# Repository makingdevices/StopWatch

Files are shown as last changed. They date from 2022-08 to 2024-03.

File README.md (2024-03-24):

<!-- Improved compatibility of back to top link: See: https://github.com/othneildrew/Best-README-Template/pull/73 -->

<!--
*** Thanks for checking out the Best-README-Template. If you have a suggestion
*** that would make this better, please fork the repo and create a pull request
*** or simply open an issue with the tag "enhancement".
*** Don't forget to give the project a star!
*** Thanks again! Now go create something AMAZING! :D
-->

<!-- PROJECT SHIELDS -->
<!--
*** I'm using markdown "reference style" links for readability.
*** Reference links are enclosed in brackets [ ] instead of parentheses ( ).
*** See the bottom of this document for the declaration of the reference variables
*** for contributors-url, forks-url, etc. This is an optional, concise syntax you may use.
*** https://www.markdownguide.org/basic-syntax/#reference-style-links
-->
[][ig-url]
[][sponsor-url]
[][stars-url]
[][issues-url]
[][linkedin-url]

<!-- PROJECT LOGO -->
<br />
<div align="center">
  <a href="https://makingdevices.com/links/">
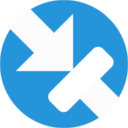
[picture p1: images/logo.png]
    
  </a>

<h3 align="center">Making Devices</h3>

  <p align="center">
    Open Source projects where we struggle with engineering, electronics, coding and who knows what else... In this case, Bytes Counter is a very simple digital tally counter, so hopefully you may find it interesting ;)
  </p>
</div>

<!-- TABLE OF CONTENTS -->
<details>
  <summary>Table of Contents</summary>
  <ol>
    <li>
      <a href="#about-the-project">About The Project</a>
      <ul>
        <li><a href="#built-with">Built With</a></li>
      </ul>
    </li>
    <li>
      <a href="#Build-one">Build one</a>
      <ul>
      </ul>
    </li>
    <li><a href="#usage">Usage</a></li>
    <li><a href="#roadmap">Roadmap</a></li>
    <li><a href="#license">License</a></li>
    <li><a href="#contact">Contact</a></li>
    <li><a href="#Sponsor">Sponsor</a></li>
  </ol>
</details>

<!-- ABOUT THE PROJECT -->
## About The Project

[Bytes Counter Shot](https://makingdevices.com/StopWatch)

This project is a simple StopWatch for measuring times on different processes or activities. The project was chosen to test some 4-layers PCBs and experiment with both the XLP (Extreme Low-Power Technology) and the pic18LF14k50 itself. You can measure from milliseconds to more than 99h. 

The PCB does not have any power button, since the project's approach is to use the XLP technology of the PIC. It only has two buttons: start/mode button and pause/stop button.

<p align="right">(<a href="#readme-top">back to top</a>)</p>

### Built With

[][PIC-url]
[][MPLAB-C-url]
[][kicad-url]
[][sponsor-url]

<p align="right">(<a href="#readme-top">back to top</a>)</p>

<!-- GETTING STARTED -->

## Build one

1. Get the gerber files for the latest version: [V1](https://github.com/makingdevices/StopWatch/blob/main/v1/Gerber/StopWatchV1.zip) 
2. Send them to a PCB manufacturer ([Our Sponsor is PCBWAY][sponsor-url])
3. Buy all the components from the [Bill Of Materials](https://github.com/makingdevices/StopWatch/blob/main/v1/StopWatch_BOM.xlsx)
4. Solder everything with the help of the [schematic](https://github.com/makingdevices/StopWatch/blob/main/v1/schematicv1.pdf)
5. Burn the [latest firmware](https://github.com/makingdevices/StopWatch/blob/main/v1/Simulation/StopWatch.hex)
6. Give us a Star to the respository ;)

Here it is an assembly video:

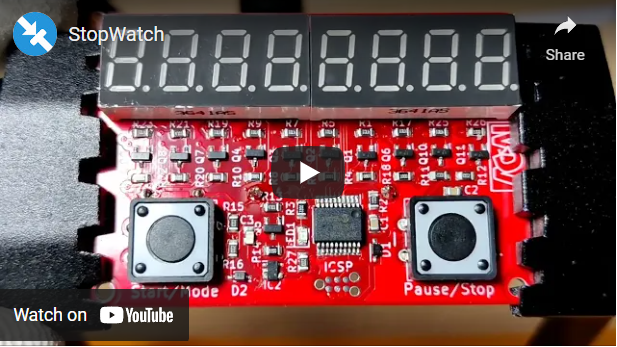
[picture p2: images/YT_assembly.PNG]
Assembly Shot
[](https://www.youtube.com/watch?v=HLl4U4vhF9I)

<p align="right">(<a href="#readme-top">back to top</a>)</p>

<!-- USAGE EXAMPLES -->
## Usage

Instructions of use:

- Pressing "Start" will start the StopWatch.
- Pressing "Pause" will stop the StopWatch.
- Long press "Start" : it will change the display mode.
- Long press "Stop" : It will reset the time to 0.
- 60s without pressing any button: Save Energy Mode -> Display off. It will still count the time. 
- 10s without pressing any button in pause mode: Deep Sleep Mode -> Display off. Not counting

<p align="right">(<a href="#readme-top">back to top</a>)</p>

<!-- ROADMAP -->
## Roadmap

- [x] Stopwatch and show it on screen
- [x] enable/disable sound when pressing buttons
- [x] Low Power Consumption
    - [x] Lower the frequency of the microcontroller at minimum
    - [x] Enter deep sleep mode automatically
    - [x] Save energy mode while still working: Display off
- [x] Measure power consumption

See the [open issues](https://github.com/makingdevices/StopWatch/issues) for a full list of proposed features (and known issues).

State: Project <b>FINISHED</b> - 18/08/2022

<p align="right">(<a href="#readme-top">back to top</a>)</p>

<!-- LICENSE -->
## License

## License

Distributed under three licenses:
- [Hardware](/License/HW_cern_ohl_s_v2.pdf)
- [Software](/License/SW_GPLv3.0.txt)
- [Documentation](/License/Documentation_CC-BY-SA-4.0.txt)

[GPL v3 License][license-url] 
<p align="right">(<a href="#readme-top">back to top</a>)</p>

<!-- CONTACT -->
## Contact

Making Devices - [@MakingDevices](https://www.instagram.com/makingdevices/)

Project Link: [https://github.com/makingdevices/StopWatch](https://github.com/makingdevices/StopWatch)

Other Links: [LinkTree](https://makingdevices.com/links/)

<p align="right">(<a href="#readme-top">back to top</a>)</p>

<!-- Sponsor -->
## Sponsor

PCBWay is the most professional PCB manufacturer for prototyping and low-volume production to work with in the world. With more than a decade in the field, They are committed to meeting the needs of their customers from different industries in terms of quality, delivery, cost-effectiveness and any other demanding requests. As Sponsor of Making Devices, they will be in charge of all the PCBs for MDV, allowing both of us to grow together in a long term partnership. We hope you take them into account for your both personal and professional prototypes or products.

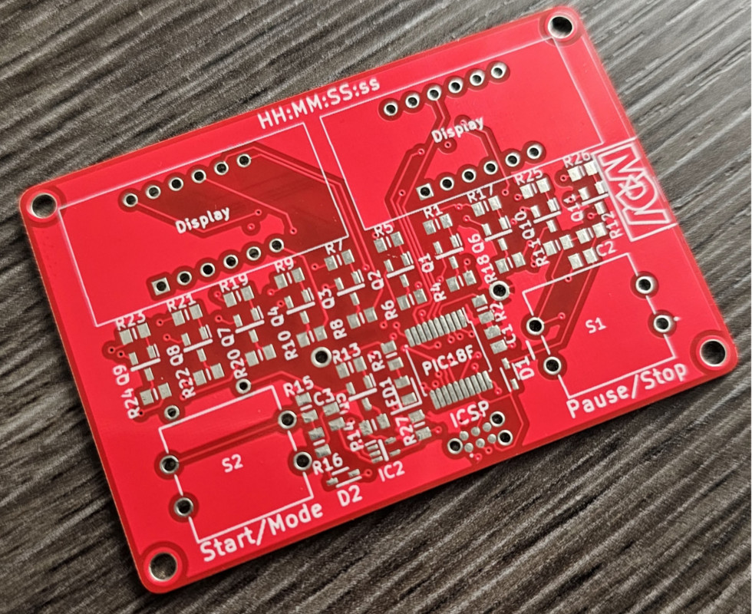
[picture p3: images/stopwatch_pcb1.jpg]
Sponsor Shot
[][sponsor-url]
[Sponsor Shot][sponsor-url]

<p align="right">(<a href="#readme-top">back to top</a>)</p>

<!-- MARKDOWN LINKS & IMAGES -->
<!-- https://www.markdownguide.org/basic-syntax/#reference-style-links -->
[contributors-shield]: https://img.shields.io/github/contributors/makingdevices/StopWatch.svg?style=for-the-badge
[contributors-url]: https://github.com/makingdevices/StopWatch/graphs/contributors
[forks-shield]: https://img.shields.io/github/forks/makingdevices/StopWatch.svg?style=for-the-badge
[forks-url]: https://github.com/makingdevices/StopWatch/network/members
[stars-shield]: https://img.shields.io/github/stars/makingdevices/StopWatch.svg?style=for-the-badge
[stars-url]: https://github.com/makingdevices/StopWatch/stargazers
[issues-shield]: https://img.shields.io/github/issues/makingdevices/StopWatch.svg?style=for-the-badge
[issues-url]: https://github.com/makingdevices/StopWatch/issues
[license-shield]: /images/license.png
[license-url]: https://github.com/makingdevices/StopWatch/tree/main/License
[linkedin-shield]: https://img.shields.io/badge/-LinkedIn-black.svg?style=for-the-badge&logo=linkedin&colorB=555
[linkedin-url]: https://www.linkedin.com/company/making-devices/
[sponsor-shield]: https://img.shields.io/badge/SPONSOR-PCBWAY-black.svg?style=for-the-badge&colorB=1200
[sponsor-url]: https://www.pcbway.com/?from=makingdevices
[sponsor-screenshot-pcb1]: /images/stopwatch_pcb1.jpg
[sponsor-screenshot-pcb2]: /images/stopwatch_pcb2.jpg
[product-screenshot]: images/screenshot.gif
[PIC]: https://img.shields.io/badge/PIC18LF14K50-000000?style=for-the-badge
[PIC-url]: http://ww1.microchip.com/downloads/en/devicedoc/40001350f.pdf
[kicad-shield]: https://img.shields.io/badge/kicad-0b03fc?style=for-the-badge&logo=kicad&logoColor=white
[kicad-url]: https://www.kicad.org/
[YT-screenshot]: images/YT_assembly.PNG
[sponsor-icon]:  https://img.shields.io/badge/-PCBWAY-black.svg?style=for-the-badge&colorB=1200
[ig-shield]: https://img.shields.io/badge/instagram-a83297?style=for-the-badge&logo=instagram&logoColor=white
[ig-url]: https://www.instagram.com/makingdevices/
[MPLAB-C]: https://img.shields.io/badge/MPLAB%20C18-DD0031?style=for-the-badge&logo=C&logoColor=white
[MPLAB-C-url]: https://www.microchip.com/en-us/development-tool/SW006011
[Svelte.dev]: https://img.shields.io/badge/Svelte-4A4A55?style=for-the-badge&logo=svelte&logoColor=FF3E00
[Svelte-url]: https://svelte.dev/
[Laravel.com]: https://img.shields.io/badge/Laravel-FF2D20?style=for-the-badge&logo=laravel&logoColor=white
[Laravel-url]: https://laravel.com
[Bootstrap.com]: https://img.shields.io/badge/Bootstrap-563D7C?style=for-the-badge&logo=bootstrap&logoColor=white
[Bootstrap-url]: https://getbootstrap.com
[JQuery.com]: https://img.shields.io/badge/jQuery-0769AD?style=for-the-badge&logo=jquery&logoColor=white
[JQuery-url]: https://jquery.com

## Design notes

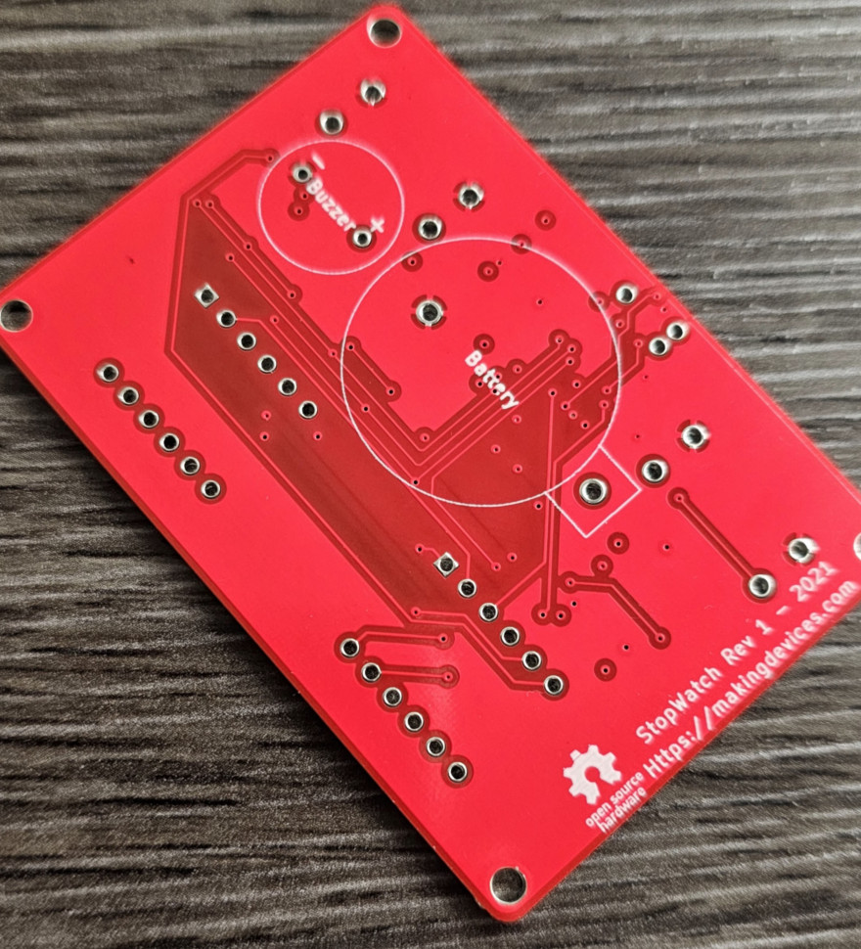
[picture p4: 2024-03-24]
images/stopwatch_pcb2.jpg

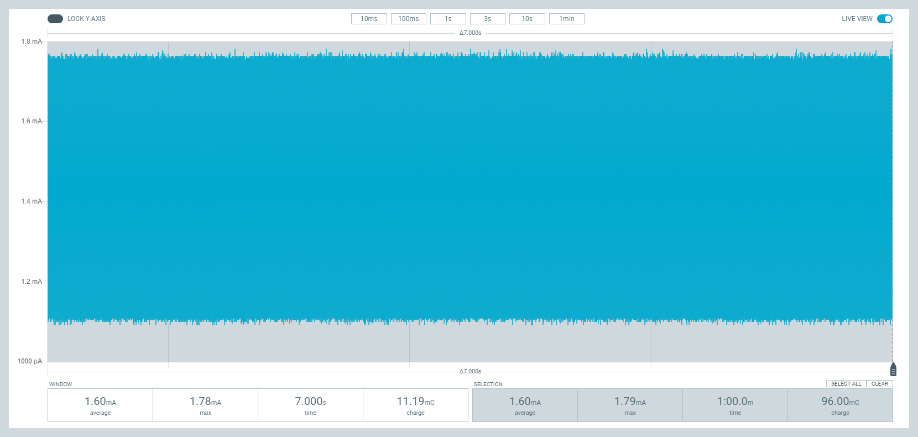
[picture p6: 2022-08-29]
v1/PowerProfile/Sleep_ScreenOFF_Counting.png

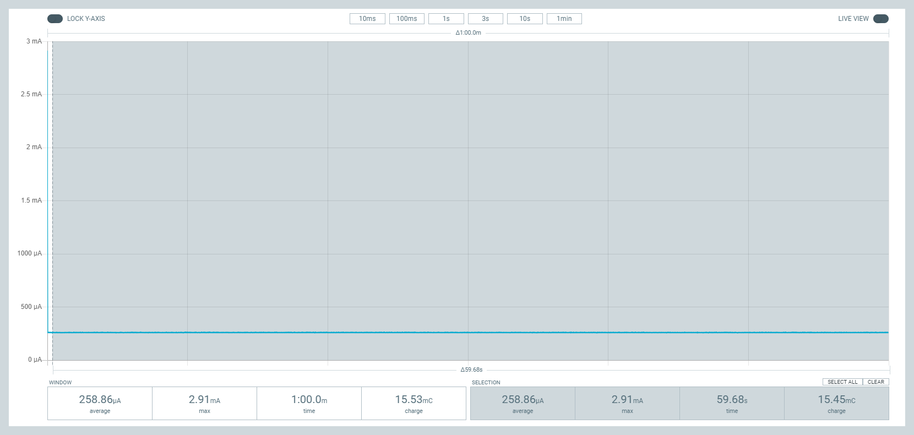
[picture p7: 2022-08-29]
v1/PowerProfile/ScreenOFF_NOTCounting.png

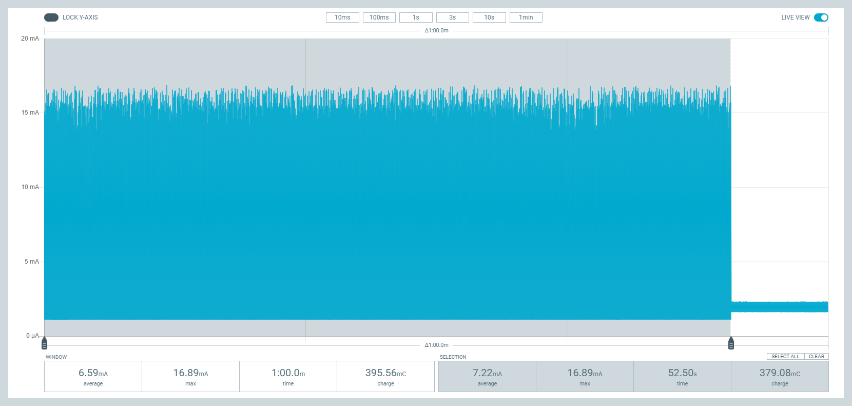
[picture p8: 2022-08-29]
v1/PowerProfile/ScreenON_Counting.png

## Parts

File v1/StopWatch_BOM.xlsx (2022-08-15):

Part | Info | Qty. | Unit Price | Ext. Price | LSCS | Link
PIC18LF14K50-I/PT | MicroProcessor | 1 | $2.0000 | $2.0000 | C219580 | https://lcsc.com/product-detail/Others_Microchip-Tech_PIC18F45K50-I-PT_Microchip-Tech-PIC18F45K50-I-PT_C219580.html
PCB v1 | PCBWAY | 1 | $3.0000 | $3.0000 |  | https://www.pcbway.com
TJ-S2012SW8TGLC2G-A5 | Green LED | 1 | $0.0291 | $0.0291 | C192319 | https://lcsc.com/product-detail/Others_TOGIALED-TJ-S2012SW8TGLC2G-A5_C192319.html
MMBT5551LT1G | NPN 600mA | 11 | $0.0250 | $0.2750 | C41095 | https://lcsc.com/product-detail/Bipolar-Transistors-BJT_ON-Semiconductor-ON-MMBT2222ALT3G_C416011.html
RTT052200FTP | 220 Ohm 0805 | 10 | $0.0024 | $0.0243 | C104105 | https://lcsc.com/product-detail/Chip-Resistor-Surface-Mount_220R-2200-1_C104105.html
NQ05W8J0101T5E | 100 Ohm 0805 | 1 | $0.0035 | $0.0035 | C965100
RTT054701FTP | 4.7k Ohm 0805 | 11 | $0.0042 | $0.0457 | C104344 | https://lcsc.com/product-detail/Chip-Resistor-Surface-Mount_4-7KR-4701-1_C104344.html
0805W8F1002T5E | 10K 0805 | 6 | $0.0028 | $0.0166 | C38522 | https://lcsc.com/product-detail/Chip-Resistor-Surface-Mount_UNI-ROYAL-Uniroyal-Elec-0805W8F1002T5E_C38522.html
TMB12A05 | Buzzer 5V | 1 | $0.1893 | $0.1893 | C96093 | https://lcsc.com/product-detail/Buzzers_Jiangsu-Huaneng-Elec-TMB12A05_C96093.html
AC0805KRX7R9BB104 | 0.1uF Cap | 3 | $0.0198 | $0.0594 | C277502 | https://lcsc.com/product-detail/Others_YAGEO-AC0805KRX7R9BB104_C277502.html
cr2032 battery holder | 2032 Battery Holder | 1 | $0.0700 | $0.0700 |  | https://es.aliexpress.com/item/33029764816.html
3461AS | Display | 2 | $0.1900 | $0.3800 |  | https://es.aliexpress.com/item/32795459724.html?spm=a2g0s.9042311.0.0.274263c0RaCynT
Tactile Push Buttons | Buttons | 2 | $0.0750 | $0.1500 |  | https://www.banggood.com/200Pcs-Tactile-Push-Button-Switch-Momentary-Tact-Caps-p-1562278.html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
ZLLS410TA | Diodes | 2 | $0.2391 | $0.4782 | C177096 | https://lcsc.com/product-detail/Schottky-Barrier-Diodes-SBD_Diodes-Incorporated-ZLLS410TA_C177096.html
74LVC1G06GW,125 | Inverter - open-drain out | 1 | $0.0534 | $0.0534 | C426704 | https://lcsc.com/product-detail/Buffers-Drivers_Nexperia-74LVC1G06GW-125_C426704.html
 |  |  |  | Total: | $6.7745

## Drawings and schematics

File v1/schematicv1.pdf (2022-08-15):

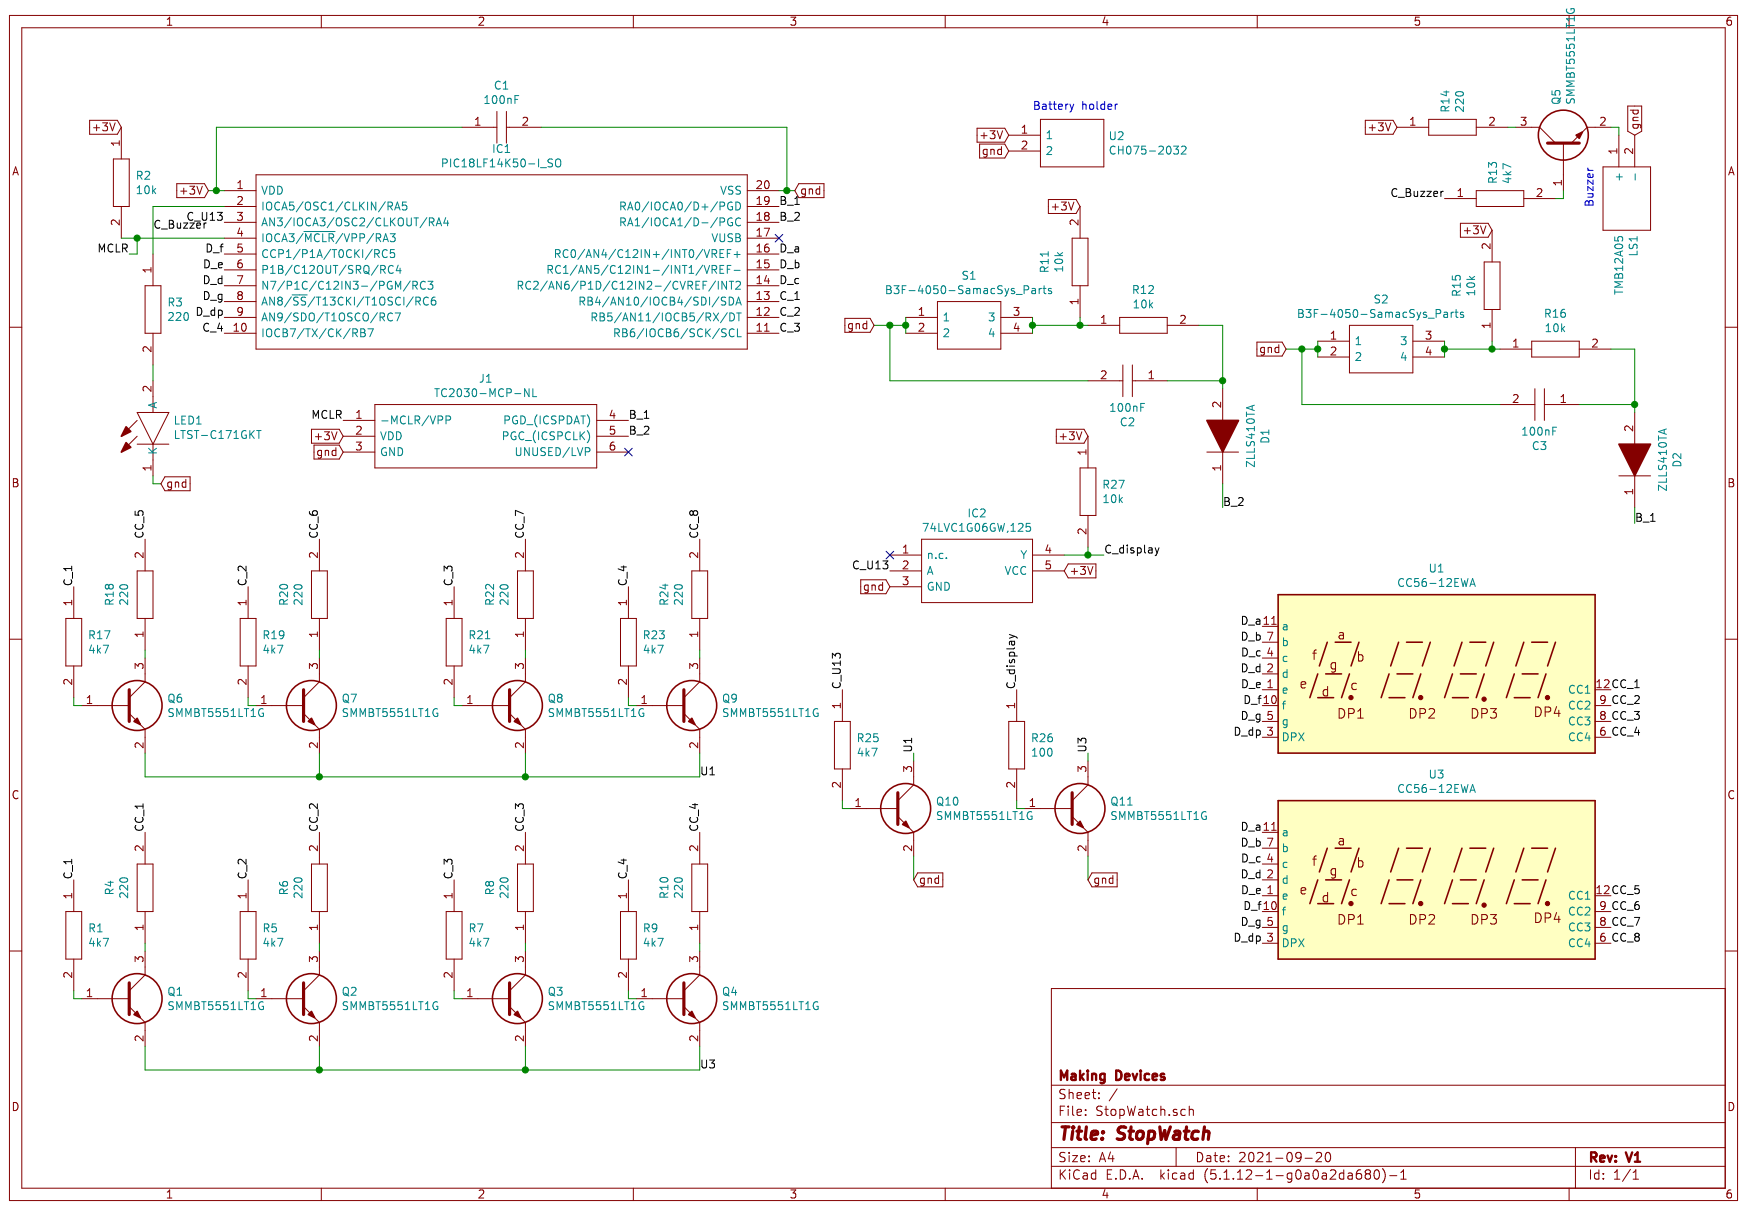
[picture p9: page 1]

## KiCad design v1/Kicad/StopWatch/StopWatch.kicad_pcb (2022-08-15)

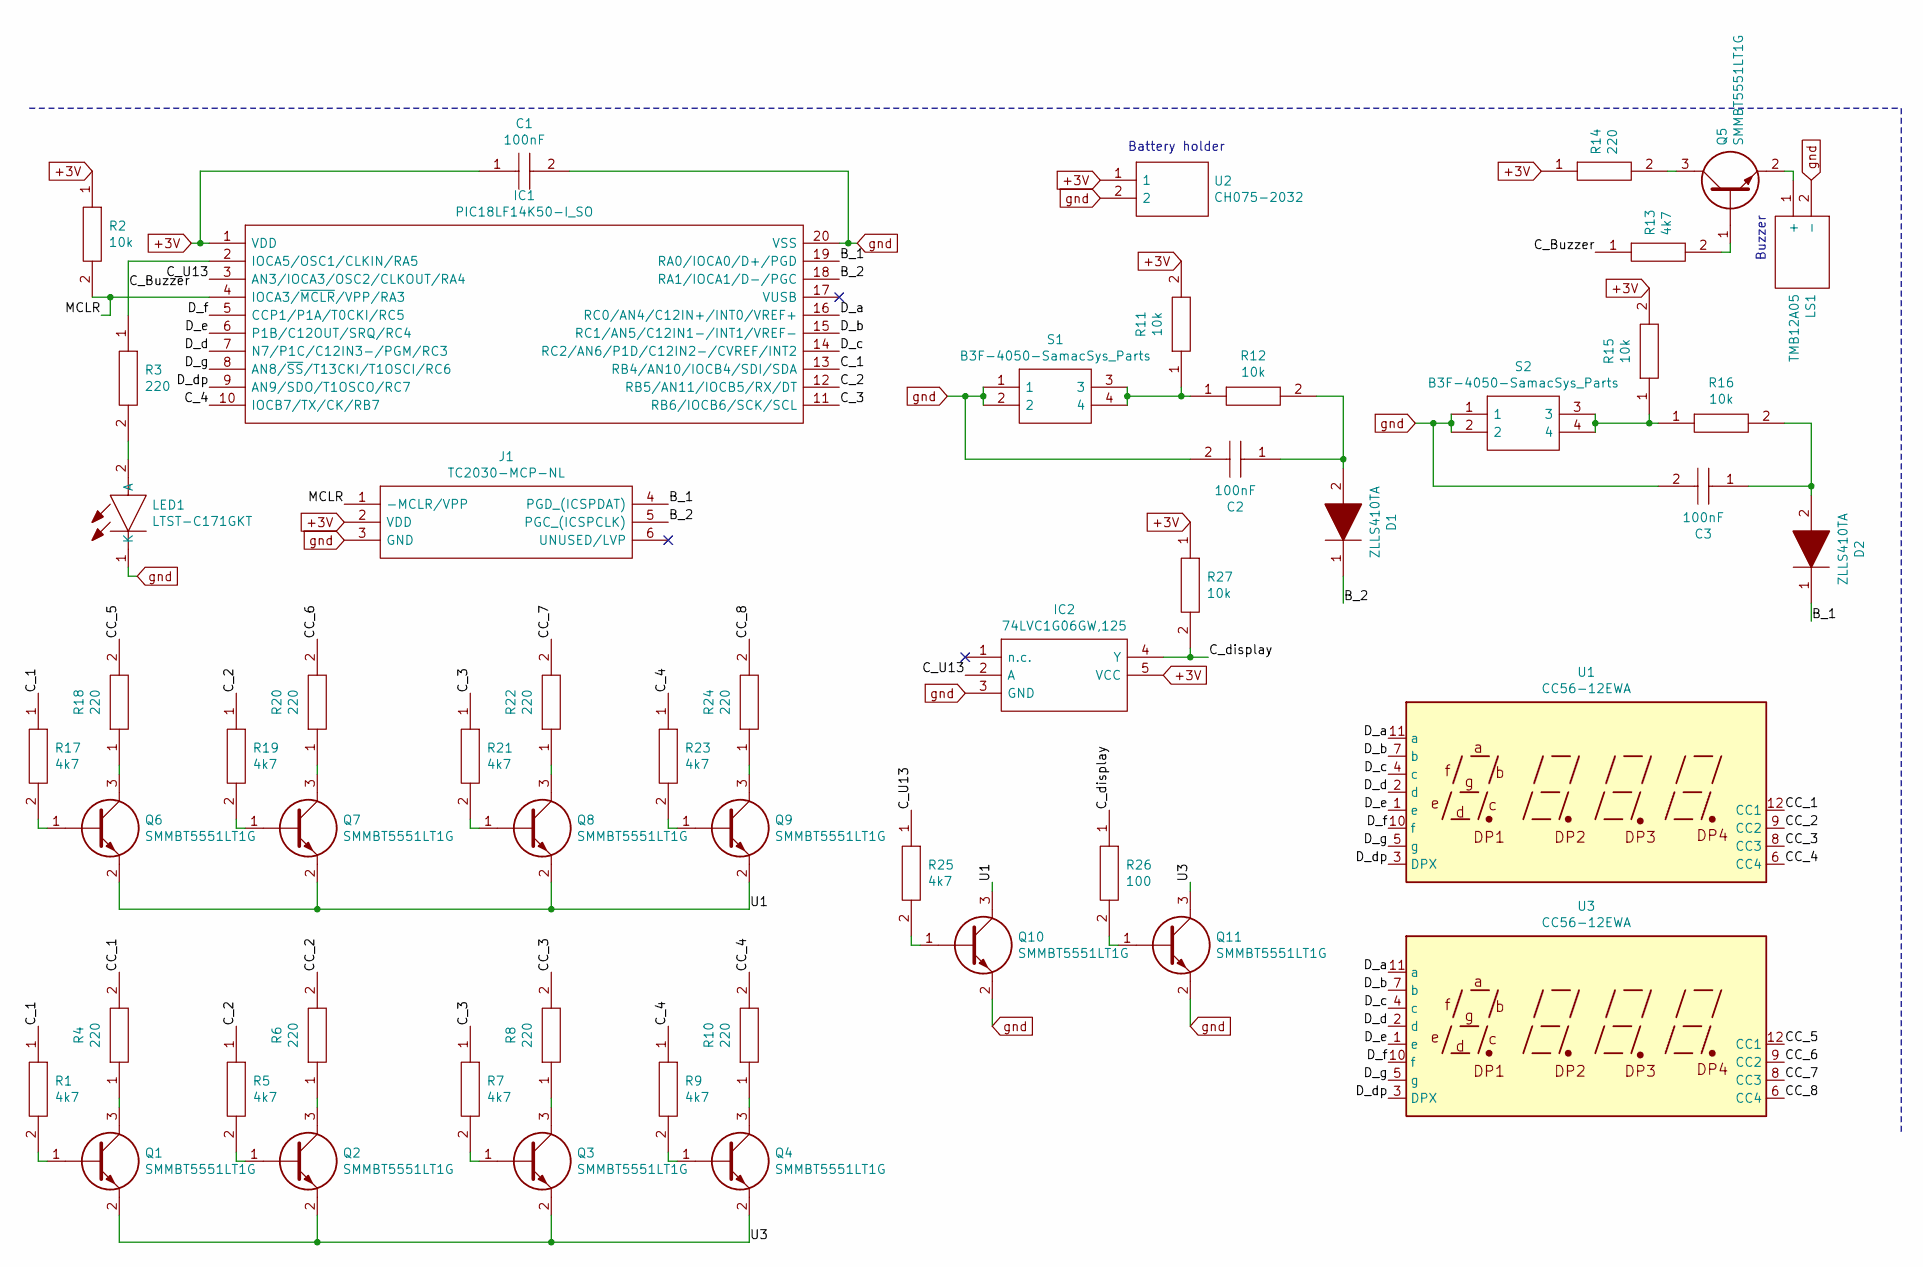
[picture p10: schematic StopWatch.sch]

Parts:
C1, C2, C3: 100nF; CAPC2012X145N; Manufacturer_Part_Number GCG21BR71H154KA01K
D1, D2: ZLLS410TA; SOD2513X120N; Manufacturer_Part_Number ZLLS410TA
IC1: PIC18LF14K50-I_SO; SSOP-20_5.3x7.2mm_P0.65mm; Manufacturer_Part_Number PIC18LF14K50-I/SO
IC2: 74LVC1G06GW,125; SOT65P212X110-5N; Manufacturer_Part_Number 74LVC1G06GW,125
J1: TC2030-MCP-NL; Manufacturer_Part_Number TC2030-MCP-NL
LED1: LTST-C171GKT; LEDC2012X90N; Manufacturer_Part_Number LTST-C171GKT
LS1: TMB12A05; Manufacturer_Part_Number TMB12A05
Q1, Q2, Q3, Q4, Q5, Q6, Q7, Q8, Q9, Q10, Q11: SMMBT5551LT1G; SOT96P237X111-3N; Manufacturer_Part_Number SMMBT5551LT1G
R1, R5, R7, R9, R13, R17, R19, R21, R23, R25: 4k7; RESC2012X65N; Manufacturer_Part_Number KTR10EZPF4220
R2, R11, R12, R15, R16, R27: 10k; RESC2012X65N; Manufacturer_Part_Number KTR10EZPF4220
R3, R4, R6, R8, R10, R14, R18, R20, R22, R24: 220; RESC2012X65N; Manufacturer_Part_Number KTR10EZPF4220
R26: 100; RESC2012X65N; Manufacturer_Part_Number KTR10EZPF4220
S1, S2: B3F-4050-SamacSys_Parts; B3F-4000; Manufacturer_Part_Number B3F-4050; Mouser Part Number 653-B3F-4050
U1, U3: CC56-12EWA; CA56-12EWA
U2: CH075-2032; CH0752032; Manufacturer_Part_Number CH075-2032

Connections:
+3V: C1.1, IC1.1 (VDD), IC2.5 (VCC), J1.2 (VDD), R2.1, R11.2, R14.1, R15.2, R27.1, U2.1
/B_1: D2.1, IC1.19 (RA0/IOCA0/D+/PGD), J1.4 (PGD_(ICSPDAT))
/B_2: D1.1, IC1.18 (RA1/IOCA1/D-/PGC), J1.5 (PGC_(ICSPCLK))
/CC_1: R4.2, U1.12 (CC1)
/CC_2: R6.2, U1.9 (CC2)
/CC_3: R8.2, U1.8 (CC3)
/CC_4: R10.2, U1.6 (CC4)
/CC_5: R18.2, U3.12 (CC1)
/CC_6: R20.2, U3.9 (CC2)
/CC_7: R22.2, U3.8 (CC3)
/CC_8: R24.2, U3.6 (CC4)
/C_1: IC1.13 (RB4/AN10/IOCB4/SDI/SDA), R1.1, R17.1
/C_2: IC1.12 (RB5/AN11/IOCB5/RX/DT), R5.1, R19.1
/C_3: IC1.11 (RB6/IOCB6/SCK/SCL), R7.1, R21.1
/C_4: IC1.10 (IOCB7/TX/CK/RB7), R9.1, R23.1
/C_Buzzer: IC1.2 (IOCA5/OSC1/CLKIN/RA5), R3.1, R13.1
/C_U13: IC1.3 (AN3/IOCA3/OSC2/CLKOUT/RA4), IC2.2 (A), R25.1
/C_display: IC2.4 (Y), R26.1, R27.2
/D_a: IC1.16 (RC0/AN4/C12IN+/INT0/VREF+), U1.11 (a), U3.11 (a)
/D_b: IC1.15 (RC1/AN5/C12IN1-/INT1/VREF-), U1.7 (b), U3.7 (b)
/D_c: IC1.14 (RC2/AN6/P1D/C12IN2-/CVREF/INT2), U1.4 (c), U3.4 (c)
/D_d: IC1.7 (N7/P1C/C12IN3-/PGM/RC3), U1.2 (d), U3.2 (d)
/D_dp: IC1.9 (AN9/SDO/T1OSCO/RC7), U1.3 (DPX), U3.3 (DPX)
/D_e: IC1.6 (P1B/C12OUT/SRQ/RC4), U1.1 (e), U3.1 (e)
/D_f: IC1.5 (CCP1/P1A/T0CKI/RC5), U1.10 (f), U3.10 (f)
/D_g: IC1.8 (AN8/~SS~/T13CKI/T1OSCI/RC6), U1.5 (g), U3.5 (g)
/MCLR: IC1.4 (IOCA3/~MCLR~/VPP/RA3), J1.1 (-MCLR/VPP), R2.2
/U1: Q6.2, Q7.2, Q8.2, Q9.2, Q10.3
/U3: Q1.2, Q2.2, Q3.2, Q4.2, Q11.3
unnamed: C2.1, D1.2, R12.2
unnamed: C3.1, D2.2, R16.2
unnamed: LED1.2 (A), R3.2
unnamed: LS1.1 (+), Q5.2
unnamed: Q1.1, R1.2
unnamed: Q1.3, R4.1
unnamed: Q2.1, R5.2
unnamed: Q2.3, R6.1
unnamed: Q3.1, R7.2
unnamed: Q3.3, R8.1
unnamed: Q4.1, R9.2
unnamed: Q4.3, R10.1
unnamed: Q5.1, R13.2
unnamed: Q5.3, R14.2
unnamed: Q6.1, R17.2
unnamed: Q6.3, R18.1
unnamed: Q7.1, R19.2
unnamed: Q7.3, R20.1
unnamed: Q8.1, R21.2
unnamed: Q8.3, R22.1
unnamed: Q9.1, R23.2
unnamed: Q9.3, R24.1
unnamed: Q10.1, R25.2
unnamed: Q11.1, R26.2
unnamed: R11.1, R12.1, S1.3, S1.4
unnamed: R15.1, R16.1, S2.3, S2.4
gnd: C1.2, C2.2, C3.2, IC1.20 (VSS), IC2.3 (GND), J1.3 (GND), LED1.1 (K), LS1.2 (-), Q10.2, Q11.2, S1.1, S1.2, S2.1, S2.2, U2.2

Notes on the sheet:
Battery holder
Buzzer

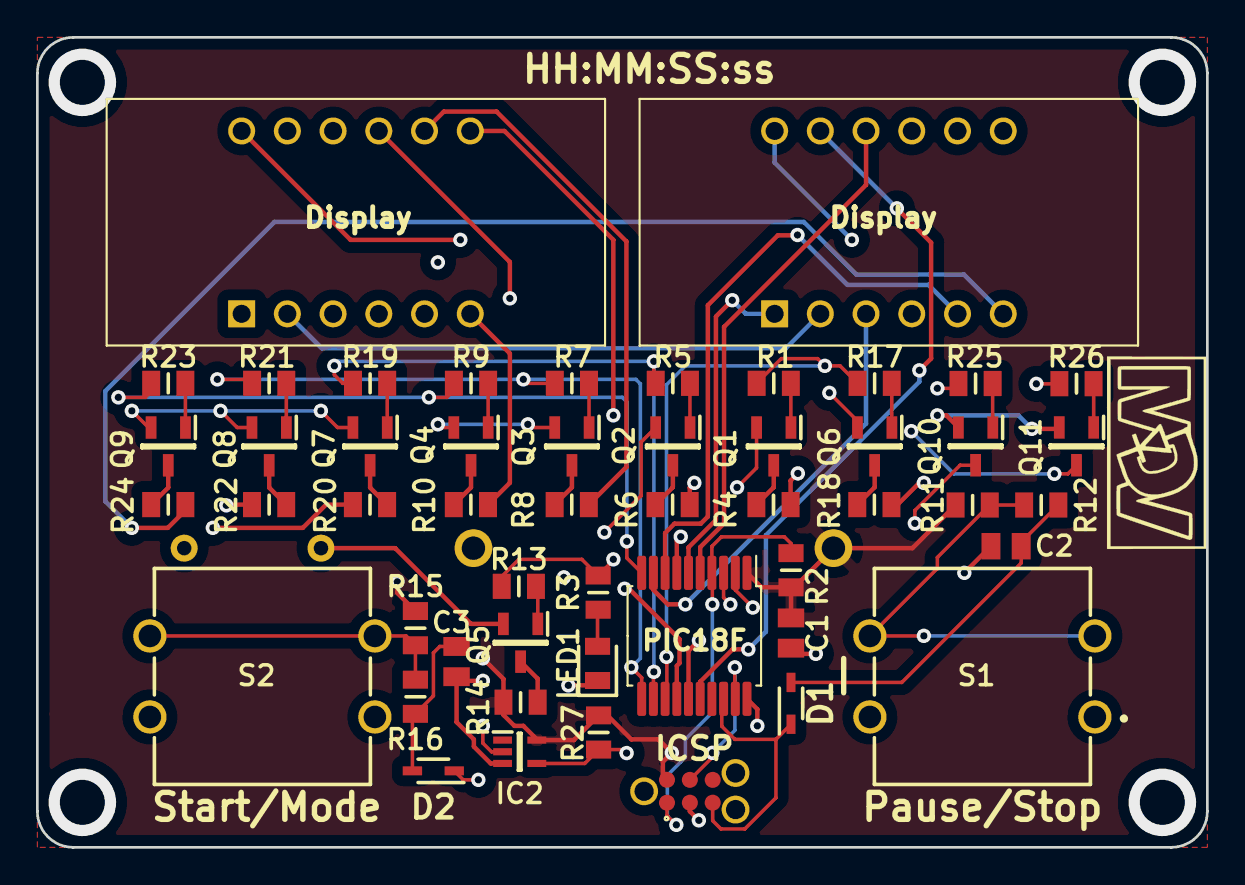
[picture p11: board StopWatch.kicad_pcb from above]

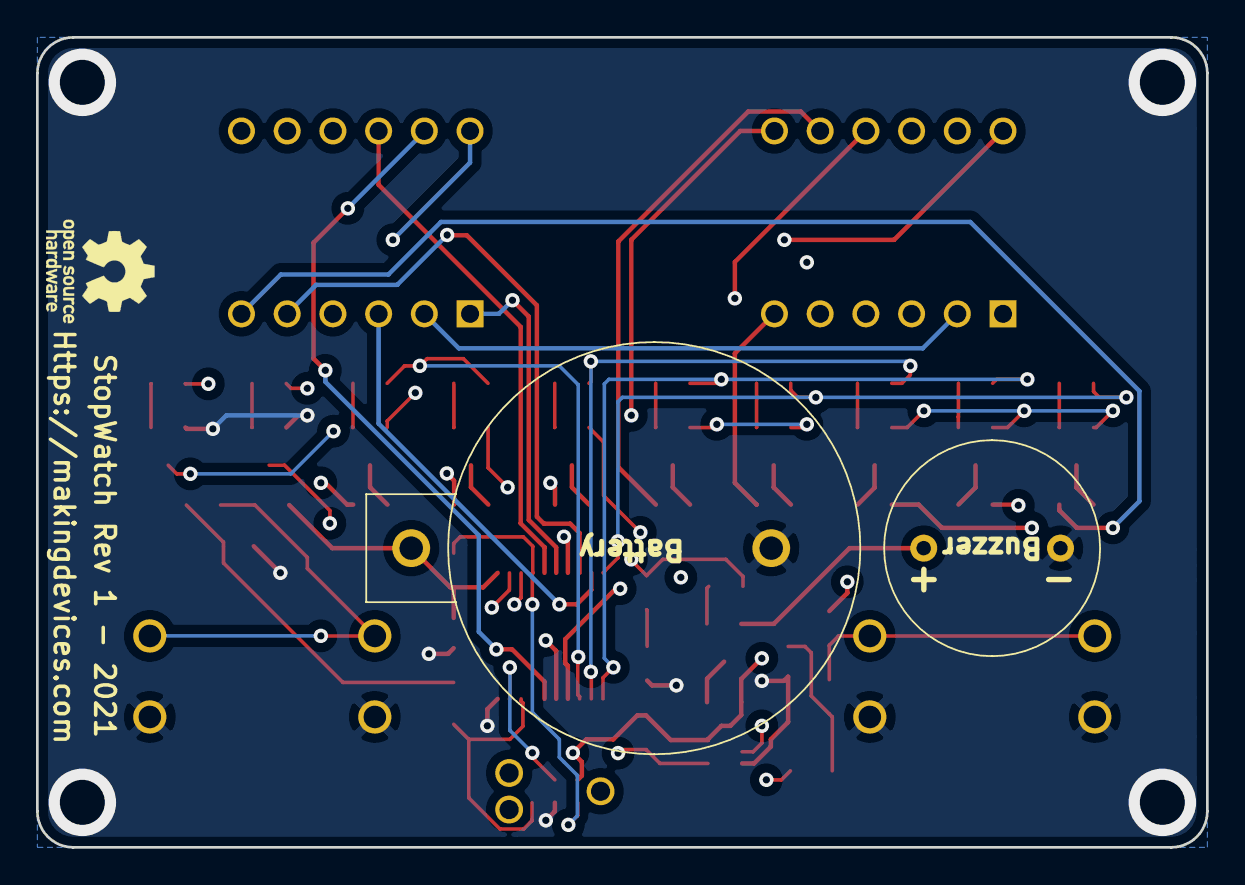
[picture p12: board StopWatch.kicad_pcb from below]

Board: 4 copper layers, 65.0 x 45.0 mm, 53 parts (2 on the bottom side), 56 nets.

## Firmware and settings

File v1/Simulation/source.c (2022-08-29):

/*	Making Devices 2021
	https://makingdevices.com
	Rubén García Segovia
	Stop Watch
*/
#include <p18f14k50.h>
#include <delays.h>

 // setup config bits 
 #pragma config PCLKEN=OFF
 #pragma config FOSC = IRC
 #pragma config BOREN = OFF 
 #pragma config WDTEN = OFF 
 #pragma config LVP = OFF  

char digit = 0;
char display = 0;
char buzz = 0; //Buzzer counter
int buzzer_time = 25; //Time for the buzzer sound

char const vector[] = {0b00111111,0b00000110,0b01011011,0b01001111,0b01100110,0b01101101,0b01111101,0b00000111,0b01111111,0b01100111,0b01111001};
char number[] = {0,0,0,0,0,0,0,0,0};
char pause = 0; // 0 = run // 1 = paused
char offset = 7; //Variable to calibrate the clock
char clock_mode = 1; //0 = 8 digits. 1 = 6 digits
char screen_mode = 1; //0 = off. 1 = ON
int reset = 0;
int sleep_time = 8000; //Time before deep sleep
int deep_sleep = 0; //Deep Sleep counter
float screen_time  = 48000; //Time to turn off the screen
float screen_sleep = 0; //Screen counter
float event_reset = 3000;
float modes = 0;
float event_modes = 3000;
char count_offset = 0;
void InitOSC(void); 
void _low_isr (void);
void _high_isr (void);
void Interrupts_enable (void);
void add_1ms (void);

#pragma code low_vector=0x18 //Low interrupt priority starts at 0x18
void low_interrupt(void)
{
_asm goto _low_isr _endasm
}

#pragma code high_vector=0x08 //High interrupt priority starts at 0x08
void high_interrupt(void)
{
_asm goto _high_isr _endasm
}
#pragma code


#pragma interrupt _low_isr

void _low_isr (void){
	
}

#pragma interrupt _high_isr
void _high_isr (void)
{	
	if(INTCONbits.TMR0IF) //Timer0 interrupt
	{
	if(PORTAbits.RA1 == 0 && PORTAbits.RA0 == 1){  //If we are pressing the button...
		screen_sleep = 0;
		reset++; //We increase reset.
		if (reset>event_reset && screen_mode == 1){ //If we have the button pressed for a while...
			buzz = 1;   //We activate buzz and LED
			LATA = 0b00100000;
			number[0] = 0;   //We reset the count.
			number[1] = 0;
			number[2] = 0;
			number[3] = 0;
			number[4] = 0;   
			number[5] = 0;
			number[6] = 0;
			number[7] = 0;
			reset = 1;
		}
		screen_mode = 1;
	} else{	
		reset = 0; //If we are not pressing nothing, reset = 0.
	}

	if(PORTAbits.RA0 == 0 && PORTAbits.RA1 == 1){  //If we are pressing the button...
		screen_sleep = 0;
		modes++; //We increase reset.
		if ((modes>event_modes) && screen_mode == 1){ //If we have the button pressed for a while...
			buzz = 1;   //We activate buzz and LED
			LATA = 0b00100000;
			if(clock_mode >0 && clock_mode < 4){
				clock_mode = 0;
			} else if (clock_mode == 0){
			 	//PORTAbits.RA4 = 0;
			 	clock_mode = 4;
			} else {
				clock_mode = 1;
			}
			modes = 1;
		}
		if(clock_mode==4 && screen_mode==0) clock_mode=1;
		screen_mode = 1;
	} else{	
		modes = 0; //If we are not pressing nothing, reset = 0.
	}

	TMR0H = 0xFC;
	TMR0L = 0xAA; 

	if(buzz > 0) {  //If the buzzer was activated
		buzz++; //increase buzz time
	} 
	if(buzz > buzzer_time) { //If the buzzer has been activated long enough
		buzz = 0;	//we stop the buzzer
		PORTA = 0;
	} 

	if (count_offset == offset){
		if(pause==0) add_1ms();
		count_offset = 0;
	} else {
		count_offset++;
	}
	LATC = 0;
		if(clock_mode < 4) {  //SET THE display into the specific position
			switch(digit){
				case 3:
					LATB = 0b10000000;
					digit = 0;
					display++;
					break;
				case 0:
					LATB = 0b01000000;
					digit = 1;
					break;
				case 1:
					LATB = 0b00100000;
					digit = 2;
					break;
				case 2:
					LATB = 0b00010000;
					digit = 3;
					break;
				default:
					break;
			}
			if (display==1){
				PORTAbits.RA4 = 0;
			} else {
				PORTAbits.RA4 = 1;
				display = 0;
			}
		}
		switch (clock_mode){  //Set the number in the C PORT
			case 0:
				if((digit+display*4)==2||(digit+display*4)==4||(digit+display*4)==6){
					LATC = (vector[number[digit+display*4]])|0b10000000;  //The dot of the display
				} else {
					LATC = vector[number[digit+display*4]];
				}
				break;
			case 3:
				if ((digit+display*4)==0 || (digit+display*4)== 7){
					LATC = 0;
				} else if((digit+display*4)==3||(digit+display*4)==5){ //The dot of the display
					LATC = (vector[number[digit+1+display*4]])|0b10000000;
				} else {
					LATC = vector[number[digit+1+display*4]];
				}
				break;
			case 2:
				if ((digit+display*4)==0 || (digit+display*4)== 7){
					LATC = 0;
					LATB = 0;
				} else if((digit+display*4)==3||(digit+display*4)==5){
					LATC = (vector[number[digit-1+display*4]])|0b10000000; //The dot of the display
				} else {
					LATC = vector[number[digit-1+display*4]];
				}
				break;
			case 1:
				if ((digit+display*4)==0 || (digit+display*4)== 1 || (digit+display*4)== 6 || (digit+display*4)== 7){
					LATC = 0;
					LATB = 0;
				} else if((digit+display*4)==4){
					LATC = (vector[number[digit-2+display*4]])|0b10000000; //The dot of the display
				} else {
					LATC = vector[number[digit-2+display*4]];
				}
				break;
			case 4:
				LATC = 0;
				LATB = 0;
				break;
			default:
				break;
		}
		if(clock_mode >0 && clock_mode < 4){
			clock_mode = 1;
			if(number[4] > 0 || number[5] > 0) clock_mode = 2;
			if(number[6] > 0 || number[7] > 0) clock_mode = 3;
		} 
	INTCONbits.TMR0IF = 0; // reset overflow bit
	}
 	if(INTCONbits.RABIF) { 
		deep_sleep = 0; //We restart the deep sleep counter
		OSCCONbits.IDLEN = 1; //Set idle mode.

		  if(PORTAbits.RA0 == 0){
			if(deep_sleep == 1){
				deep_sleep = 0;
			} else {
				if(clock_mode == 4 && pause == 1) clock_mode = 1;
				pause = 0;
			}
		  }			
		  if(PORTAbits.RA1 == 0){
			if(deep_sleep == 1){
				deep_sleep = 0;
			} else pause = 1;
		  }	
          INTCONbits.RABIF = 0;			//Clear RAB Interrupt Flag 
    } 

	if(pause == 1) deep_sleep++;  //We increase time before sleep
	else deep_sleep = 0;
	screen_sleep++; //Screen time

	if (deep_sleep > sleep_time){ //If the time for sleep has come
		OSCCONbits.IDLEN = 0; //Prepare the microchip for deep sleep.
		LATB = 0b00000000; //turn off the display
		LATC = 0b00000000;
	}
	if (screen_sleep > screen_time){ //If the time for screen has come
		screen_mode = 0;
        clock_mode = 4;
	}
}

/* ****************** MAIN ****************** */
char a = 0;
void main(void)
{
	if(a==0){
		a = 1;
		InitOSC();     //Internal OSC 16MHz 
    	Interrupts_enable(); //Enable RA0 & RA1 interrupts
		TRISB =0;
		TRISC =0;
		TRISAbits.RA4 = 0;
		TRISAbits.RA5 = 0;
		PORTAbits.RA5 = 0;
		PORTAbits.RA4 = 1;
		OSCCONbits.IDLEN = 1;
	}
	Sleep();
}

 void InitOSC(void) 
 {    
      OSCCON  = 0b01010111;   //Internal 16MHz    
 } 
 void Interrupts_enable(void) 
 {    
	TRISA = 0xFF; //A port as input
    INTCON2bits.RABPU = 0; // Enable Pull-UP on port A-B
    INTCON2bits.RABIP = 1; // Change on port = High priority
	IOCA  = 0b000000011;        //Enable Interrupt on Change for Pin 4 of Port A 
    INTCONbits.RABIE = 1;      //Enable RA and RB Port Change Interrupt 

	T0CONbits.T08BIT = 0; //16 bit
	T0CONbits.T0CS = 0; //Internal Instruction Cycle Clock
	T0CONbits.PSA = 1; 

	T0CONbits.T08BIT = 0;
	T0CONbits.T0CS = 0;
	T0CONbits.PSA = 1;
	TMR0H = 0xFC;
	TMR0L = 0xAA; 
	T0CONbits.TMR0ON = 1;

	RCONbits.IPEN       = 1;    //Enable Interrupt Priorities
    INTCONbits.GIEL     = 1;    //Enable Low Priority Interrupt
    INTCONbits.GIEH     = 1;    //Enable high priority interrupts        
    INTCONbits.TMR0IE   = 1;    //Enable Timer0 Interrupt
    INTCON2bits.TMR0IP  = 1;    //TMR0 set to low Priority Interrupt
    INTCONbits.TMR0IF = 0;  // T0 int flag bit cleared before starting
    T0CONbits.TMR0ON = 1;   // timer0 START
	INTCONbits.GIE = 1; 		   //Enable all unmasked interrupts   
 } 
 
void add_1ms(void){
char i = 0;
number[0]++;
	for(i=0; i<7;i++){
			if(number[3]>5){
				number[3] = 0;
				number[4]++;
			}
			if(number[5]>5){
				number[5] = 0;
				number[6]++;
			}
			if(number[i]>9){
				number[i+1]++;
				number[i] = 0;
			}
			if(number[i]<0){
				number[i+1]--;
				number[i] = 9;
			}
	}
}

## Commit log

2022-08-15 Updating files
    [StopWatch-B_Cu.gbr, StopWatch-B_Mask.gbr, StopWatch-B_Paste.gbr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]
2022-08-15 new files
    BOM and Schematic in PDF
    [StopWatch_BOM.xlsx]
2022-12-19 Update root folders
    [StopWatch-B_Cu.gbr, StopWatch-B_Mask.gbr, StopWatch-B_Paste.gbr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]
